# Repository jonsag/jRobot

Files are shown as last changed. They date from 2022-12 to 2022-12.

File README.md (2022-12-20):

# jRobot

My take on B-ROBOT found at https://github.com/jjrobots/B-ROBOT

## WiFI Remote

[https://play.google.com/store/apps/details?id=com.realwox.wifirccontroller&hl=en_US&gl=US](https://play.google.com/store/apps/details?id=com.realwox.wifirccontroller&hl=en_US&gl=US)
[https://play.google.com/store/apps/details?id=com.lacour.vincent.wificaresp8266&hl=en_US&gl=US](https://play.google.com/store/apps/details?id=com.lacour.vincent.wificaresp8266&hl=en_US&gl=US)

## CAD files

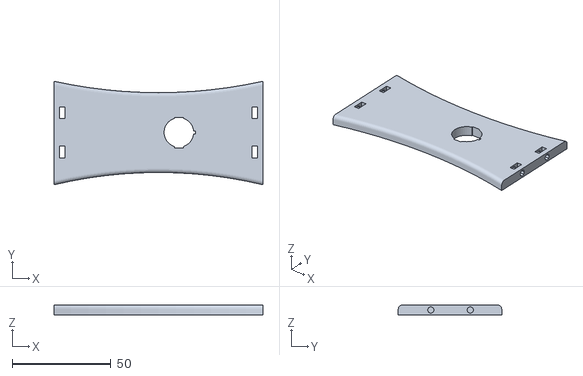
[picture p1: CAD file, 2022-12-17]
stl/top SHELF.stl
106.1 x 52.6 x 5.00

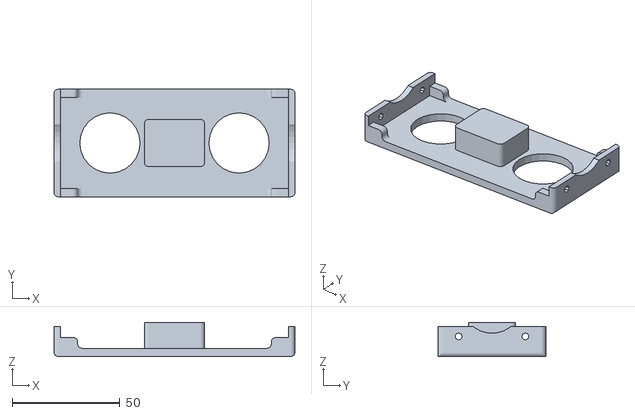
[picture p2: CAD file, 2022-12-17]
stl/motor SHELF.stl
112.0 x 50.0 x 15.9

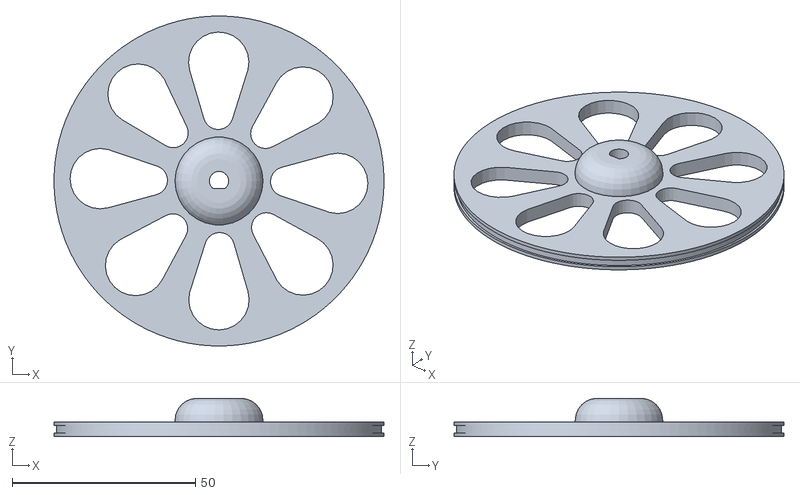
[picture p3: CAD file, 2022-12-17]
stl/Regular Wheel.stl
90.0 x 90.0 x 10.5

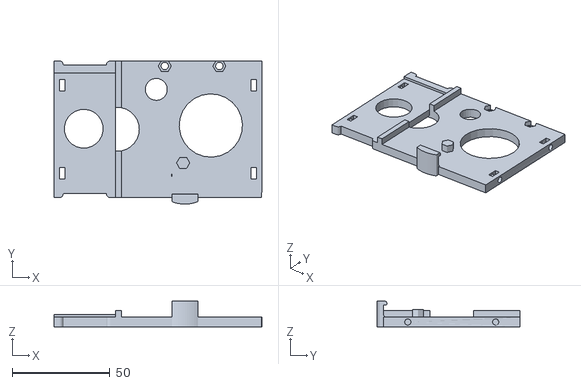
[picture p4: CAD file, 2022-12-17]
stl/Electronics SHELF.stl
106.2 x 73.1 x 13.2

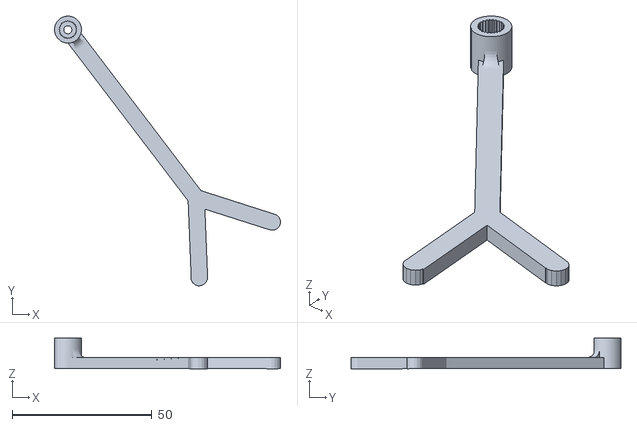
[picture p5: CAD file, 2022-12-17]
stl/regular ARM.stl
80.9 x 96.6 x 10.9

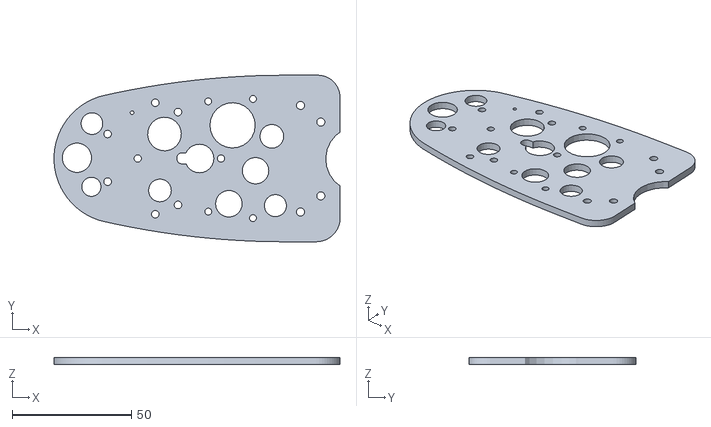
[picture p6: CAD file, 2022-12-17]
stl/Lateral.stl
120.1 x 70.0 x 3.00

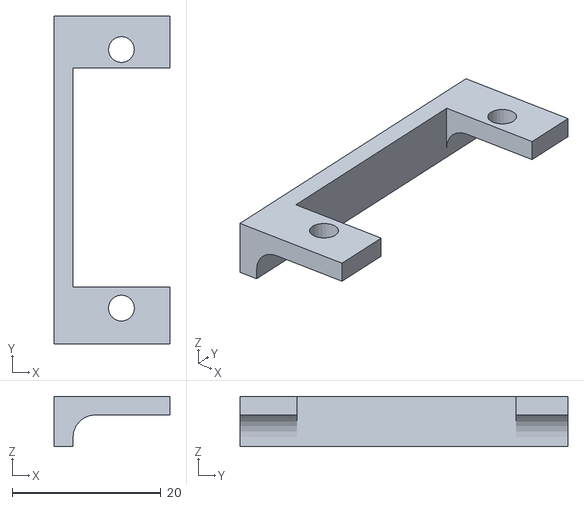
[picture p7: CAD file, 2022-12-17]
stl/servo holder.stl
15.5 x 44.0 x 6.78

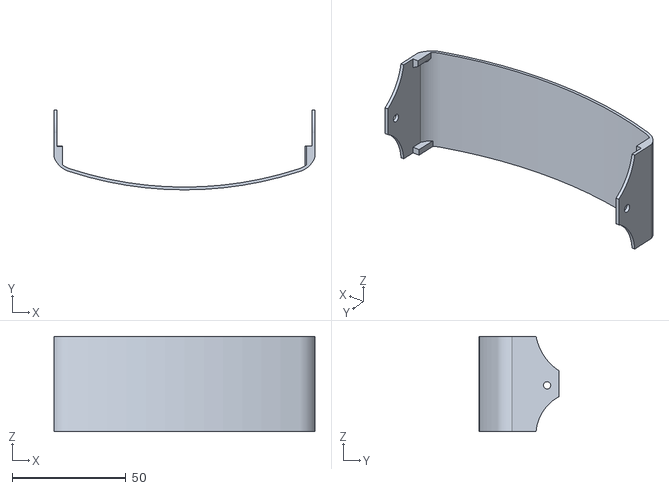
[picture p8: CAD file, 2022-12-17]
stl/Bumper.stl
114.5 x 35.0 x 41.9

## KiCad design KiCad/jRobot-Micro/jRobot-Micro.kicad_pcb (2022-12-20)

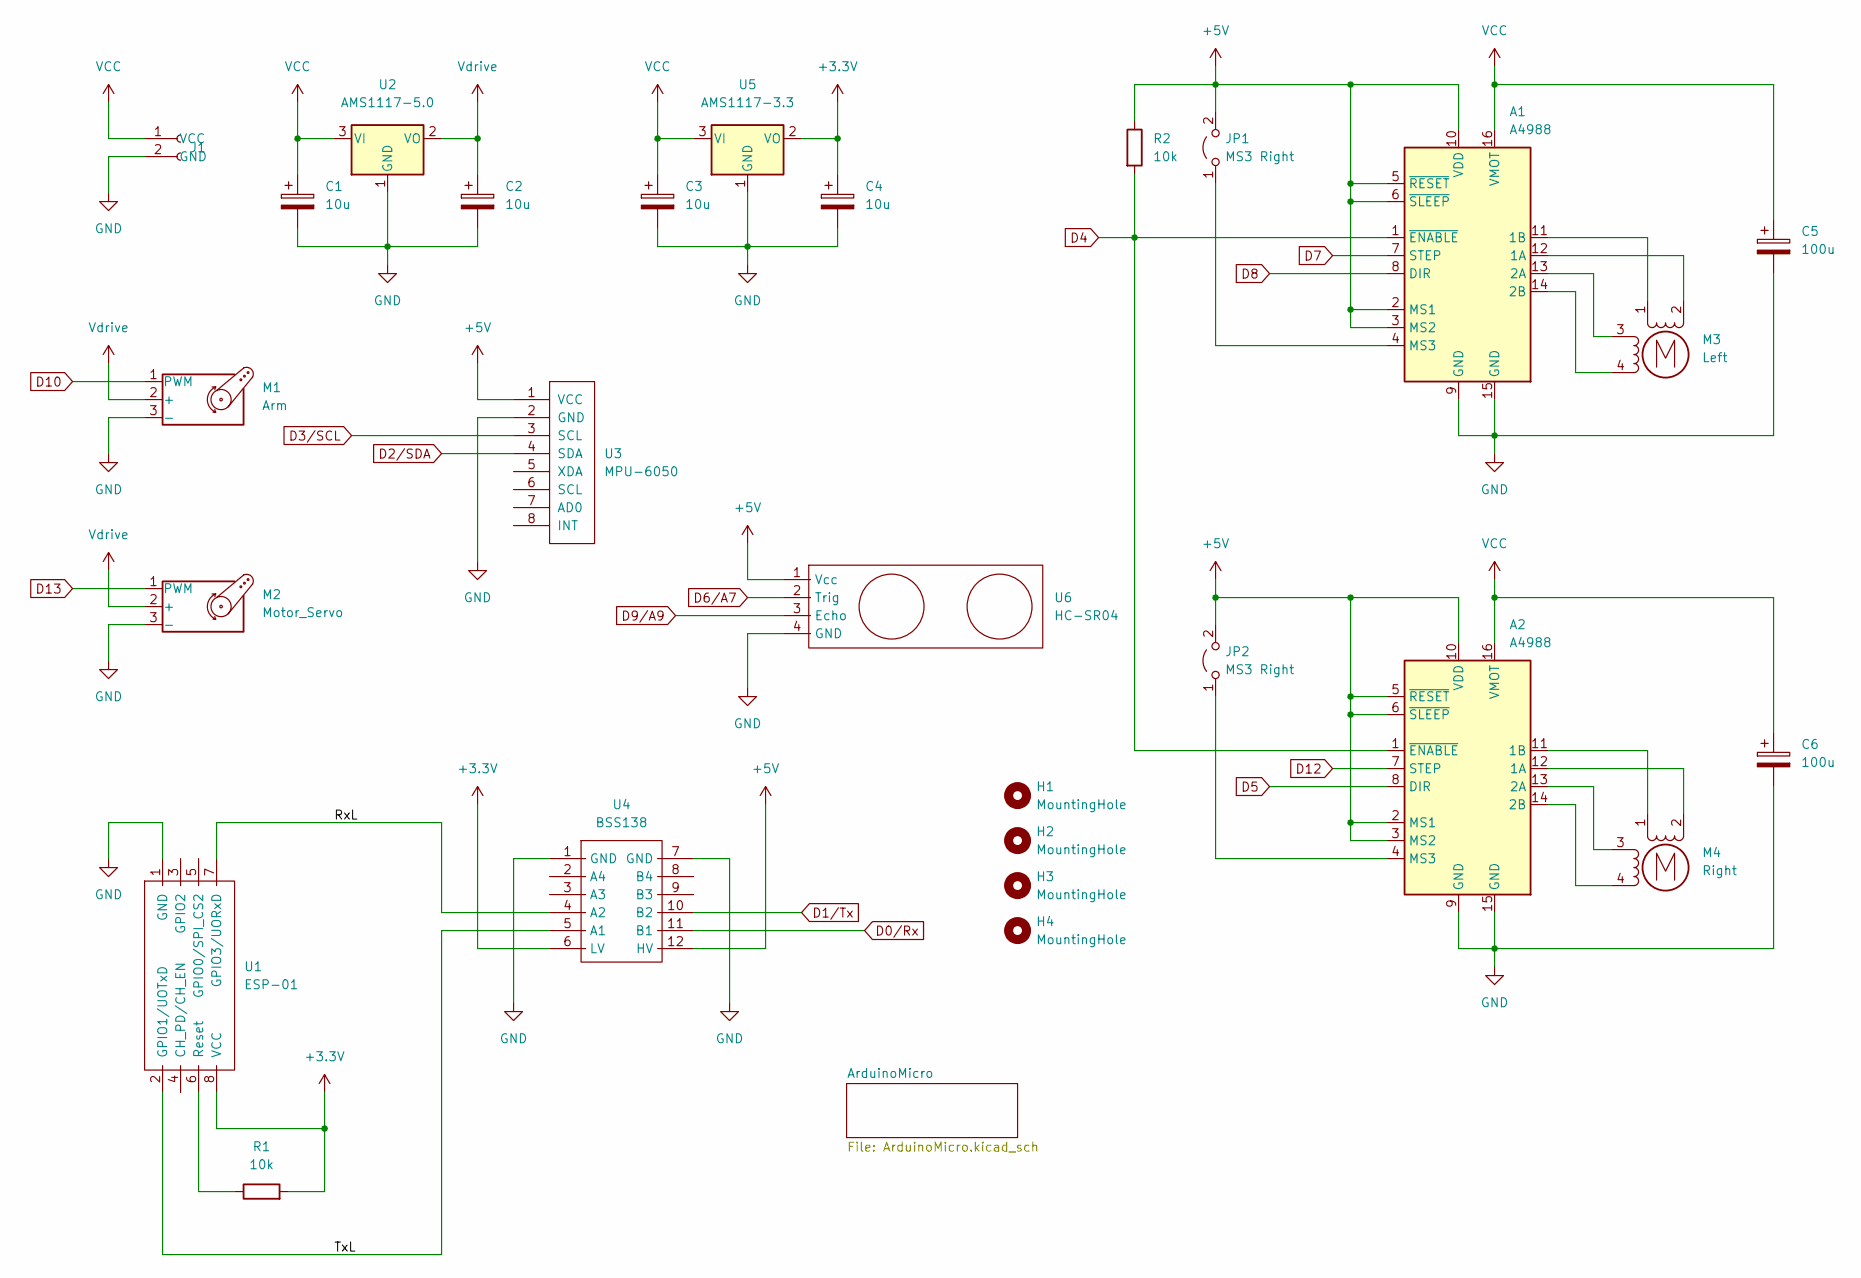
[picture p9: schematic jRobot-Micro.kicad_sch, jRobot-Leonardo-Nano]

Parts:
A1, A2: A4988; Pololu_Breakout-16_15.2x20.3mm_large
C1, C2, C3, C4: 10u; CP_Radial_D5.0mm_P2.00mm_larger
C5, C6: 100u; CP_Radial_D5.0mm_P2.00mm_larger
H1, H2, H3, H4: MountingHole; MountingHole_3.2mm_M3
J1: 2-pin_power_input_header
JP1, JP2: MS3 Right; Jumper_1x02_P2.54mm_large
M1: Arm; 3-pin JST Servo
M2: Motor_Servo
M3: Left; PhoenixPCB_2-Pole_Stepper_Connector
M4: Right; PhoenixPCB_2-Pole_Stepper_Connector
R1, R2: 10k; R_Axial_DIN0207_L6.3mm_D2.5mm_P10.16mm_Horizontal_large
U1: ESP-01; ESP-01_w_pin_socket_large
U2: AMS1117-5.0; SOT-223-3_TabPin2
U3: MPU-6050; GY-521_MPU6050_w_header_large
U4: BSS138; 4-channel_I2C_level_shifter_BSS138_large
U5: AMS1117-3.3; SOT-223-3_TabPin2
U6: HC-SR04; 4-pin JST HC-SR04 Sonar

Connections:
+3.3V: C4.1, R1.2, U1.8 (VCC), U4.6 (LV), U5.2 (VO); also elsewhere on the board
+5V: A1.2 (MS1), A1.3 (MS2), A1.5 (~RESET), A1.6 (~SLEEP), A1.10 (VDD), A2.2 (MS1), A2.3 (MS2), A2.5 (~RESET), A2.6 (~SLEEP), A2.10 (VDD), JP1.2 (B), JP2.2 (B), R2.1, U3.1 (VCC), U4.12 (HV), U6.1 (Vcc); also elsewhere on the board
/RxL: U1.7 (GPIO3/UORxD), U4.4 (A2)
/TxL: U1.2 (GPIO1/UOTxD), U4.5 (A1)
D0/Rx: U4.11 (B1); also elsewhere on the board
D1/Tx: U4.10 (B2); also elsewhere on the board
D2/SDA: U3.4 (SDA); also elsewhere on the board
D3/SCL: U3.3 (SCL); also elsewhere on the board
D4: A1.1 (~ENABLE), A2.1 (~ENABLE), R2.2
D5: A2.8 (DIR); also elsewhere on the board
D6/A7: U6.2 (Trig); also elsewhere on the board
D7: A1.7 (STEP); also elsewhere on the board
D8: A1.8 (DIR)
D9/A9: U6.3 (Echo); also elsewhere on the board
D10: M1.1 (PWM)
D12: A2.7 (STEP)
GND: A1.9 (GND), A1.15 (GND), A2.9 (GND), A2.15 (GND), C1.2, C2.2, C3.2, C4.2, C5.2, C6.2, J1.2 (GND), M1.3 (-), M2.3 (-), U1.1 (GND), U2.1 (GND), U3.2 (GND), U4.1 (GND), U4.7 (GND), U5.1 (GND), U6.4 (GND); also elsewhere on the board
unnamed: A1.4 (MS3), JP1.1 (A)
unnamed: A1.11 (1B), M3.1
unnamed: A1.12 (1A), M3.2 (-)
unnamed: A1.13 (2A), M3.3
unnamed: A1.14 (2B), M3.4
unnamed: A2.4 (MS3), JP2.1 (A)
unnamed: A2.11 (1B), M4.1
unnamed: A2.12 (1A), M4.2 (-)
unnamed: A2.13 (2A), M4.3
unnamed: A2.14 (2B), M4.4
unnamed: R1.1, U1.6 (Reset)
VCC: A1.16 (VMOT), A2.16 (VMOT), C1.1, C3.1, C5.1, C6.1, J1.1 (VCC), U2.3 (VI), U5.3 (VI); also elsewhere on the board
Vdrive: C2.1, M1.2 (+), M2.2 (+), U2.2 (VO)

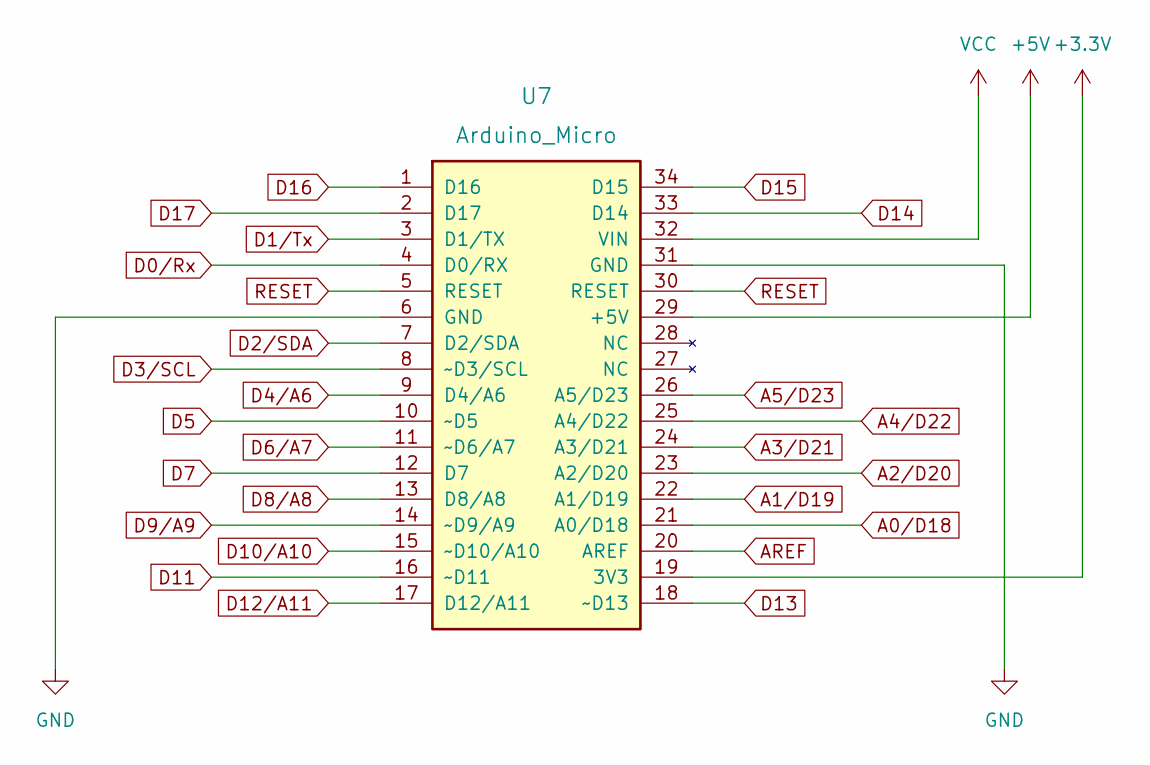
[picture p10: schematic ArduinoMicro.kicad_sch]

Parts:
U7: Arduino_Micro; Arduino_Micro large

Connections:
+3.3V: U7.19 (3V3); also elsewhere on the board
+5V: U7.29 (+5V); also elsewhere on the board
A0/D18: U7.21 (A0/D18)
A1/D19: U7.22 (A1/D19)
A2/D20: U7.23 (A2/D20)
A3/D21: U7.24 (A3/D21)
A4/D22: U7.25 (A4/D22)
A5/D23: U7.26 (A5/D23)
AREF: U7.20 (AREF)
D0/Rx: U7.4 (D0/RX); also elsewhere on the board
D1/Tx: U7.3 (D1/TX); also elsewhere on the board
D2/SDA: U7.7 (D2/SDA); also elsewhere on the board
D3/SCL: U7.8 (~D3/SCL); also elsewhere on the board
D4/A6: U7.9 (D4/A6)
D5: U7.10 (~D5); also elsewhere on the board
D6/A7: U7.11 (~D6/A7); also elsewhere on the board
D7: U7.12 (D7); also elsewhere on the board
D8/A8: U7.13 (D8/A8)
D9/A9: U7.14 (~D9/A9); also elsewhere on the board
D10/A10: U7.15 (~D10/A10)
D11: U7.16 (~D11)
D12/A11: U7.17 (D12/A11)
D13: U7.18 (~D13)
D14: U7.33 (D14)
D15: U7.34 (D15)
D16: U7.1 (D16)
D17: U7.2 (D17)
GND: U7.6 (GND), U7.31 (GND); also elsewhere on the board
RESET: U7.5 (RESET), U7.30 (RESET)
VCC: U7.32 (VIN); also elsewhere on the board

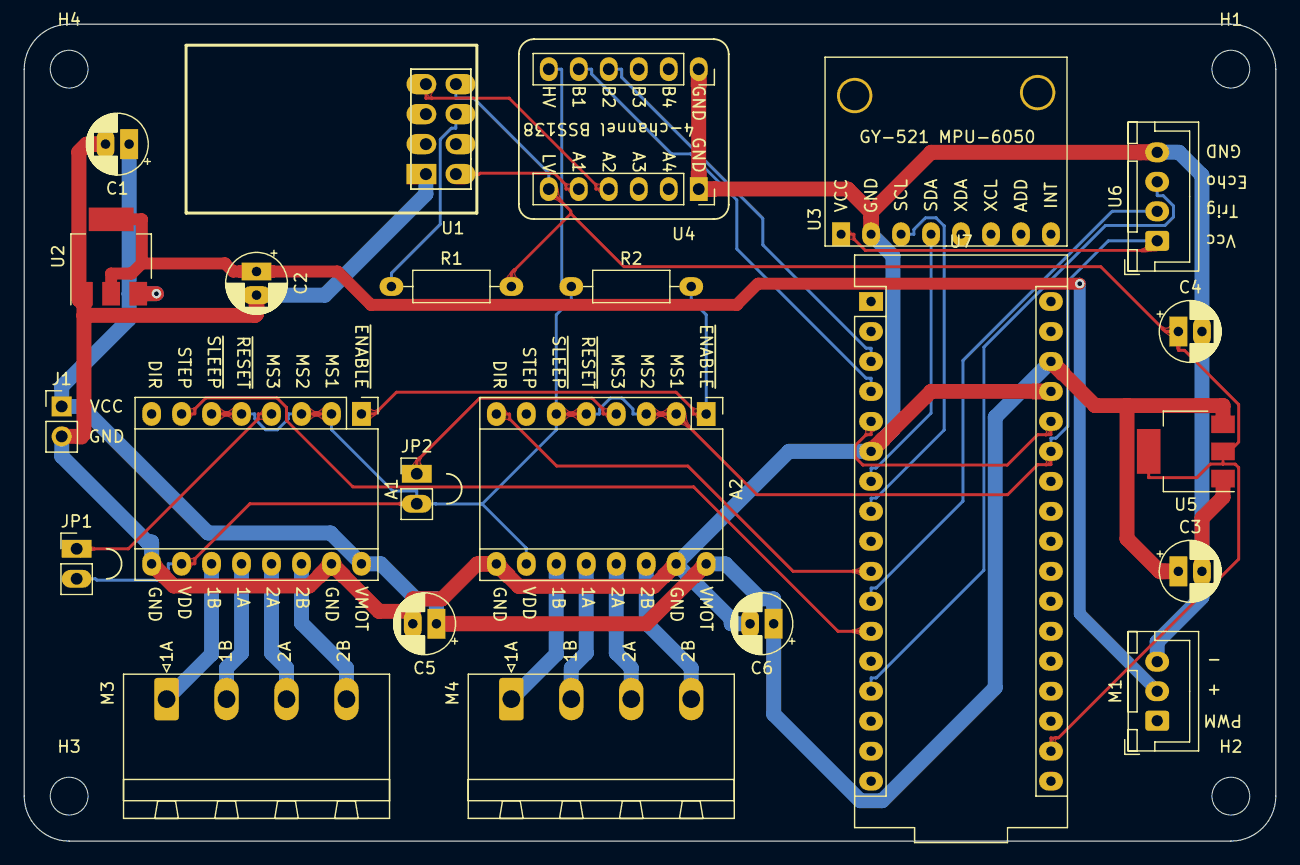
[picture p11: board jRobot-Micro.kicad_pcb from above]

Board: 2 copper layers, 106.0 x 69.2 mm, 27 parts (0 on the bottom side), 28 nets.

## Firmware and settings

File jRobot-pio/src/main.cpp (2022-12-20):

#include <Arduino.h>

// B-ROBOT  SELF BALANCE ARDUINO ROBOT WITH STEPPER MOTORS
// JJROBOTS BROBOT KIT: (Arduino Leonardo + BROBOT ELECTRONIC BRAIN v2 + STEPPER MOTOR drivers)
// This code is prepared for new BROBOT shield v2.0 with ESP8266 Wifi module
// You need to install libraries JJROBOTS_OSC, JJROBOTS_BROBOT, I2Cdev and MPU6050 (from Github repository)
// Author: JJROBOTS.COM (Jose Julio & Juan Pedro)
// Date: 02/09/2014
// Updated: 26/10/2015
// Version: 2.21
// License: GPL v2
// Project URL: http://jjrobots.com/b-robot (Features,documentation,build instructions,how it works, SHOP,...)
// New updates:
//   - New default parameters specially tuned for BROBOT EVO version
//   - Support for TouchMessages(/z). Main controls resets when user lift the fingers
//   - BROBOT sends the battery status to the interface
//   Remember to update the libraries and install the new TouchOSC layout
//  Thanks to our users on the forum for the new ideas. Specially sasa999, KomX, ...

// The board needs at least 10-15 seconds with no motion (robot steady) at beginning to give good values...
// MPU6050 IMU using internal DMP processor. Connected via I2C bus
// Angle calculations and control part is running at 200Hz from DMP solution
// DMP is using the gyro_bias_no_motion correction method.

// The robot is OFF when the angle is high (robot is horizontal). When you start raising the robot it
// automatically switch ON and start a RAISE UP procedure.
// You could RAISE UP the robot also with the robot arm servo [OPTIONAL] (Push1 on the interface)
// To switch OFF the robot you could manually put the robot down on the floor (horizontal)

// We use a standard PID controllers (Proportional, Integral derivative controller) for robot stability
// More info on the project page
// We have a PI controller for speed control and a PD controller for stability (robot angle)
// The output of the control (motors speed) is integrated so it´s really an acceleration not an speed.

// We control the robot from a WIFI module using OSC standard UDP messages (JJROBOTS_OSC library)
// You need an OSC app to control de robot (example: TouchOSC for IOS and Android)
// Join the module Wifi Access Point (by default: JJROBOTS) with your Smartphone/Tablet...
// Install the BROBOT layout into the OSC app (Touch OSC) and start play! (read the project page)
// OSC controls:
//    fader1: Throttle (0.0-1.0) OSC message: /1/fader1
//    fader2: Steering (0.0-1.0) OSC message: /1/fader2
//    push1: Move servo arm (and robot raiseup) OSC message /1/push1 [OPTIONAL]
//    if you enable the touchMessage on TouchOSC options, controls return to center automatically when you lift your fingers
//    toggle1: Enable PRO mode. On PRO mode steering and throttle are more aggressive
//    PAGE2: PID adjustments [optional][don´t touch if you don´t know what you are doing...;-) ]

#include "config.h"
#include "dmpFunctions.h"
#include "PIDController.h"
#include "delay.h"
#include "timers.h"
#include "motorControl.h"
#include "oscControl.h"
#include "ESPSetup.h"

// INITIALIZATION
void setup()
{
  // STEPPER PINS ON JJROBOTS BROBOT BRAIN BOARD
  pinMode(ENABLE_MOTORS_PIN, OUTPUT);    // ENABLE MOTORS
  pinMode(STEP_MOTOR_1_PIN, OUTPUT);    // STEP MOTOR 1 PORTE,6
  pinMode(DIR_MOTOR_1_PIN, OUTPUT);    // DIR MOTOR 1  PORTB,4
  pinMode(STEP_MOTOR_2_PIN, OUTPUT);   // STEP MOTOR 2 PORTD,6
  pinMode(DIR_MOTOR_2_PIN, OUTPUT);    // DIR MOTOR 2  PORTC,6
  digitalWrite(DISABLE_MOTORS_PIN, HIGH); // Disable motors

  pinMode(SERVO_1_PIN, OUTPUT); // Servo1 (arm)
  pinMode(SERVO_2_PIN, OUTPUT); // Servo2

  Serial.begin(115200); // Serial output to console

  // Wifi module initialization: Wifi module should be pre configured (use another sketch to configure the module)

  // Initialize I2C bus (MPU6050 is connected via I2C)
  Wire.begin();
  // I2C 400Khz fast mode
  TWSR = 0;
  TWBR = ((16000000L / I2C_SPEED) - 16) / 2;
  TWCR = 1 << TWEN;

#if DEBUG > 0
  delay(9000);
#else
  delay(2000);
#endif
  Serial.println("BROBOT by JJROBOTS v2.2");
  Serial.println("Initializing I2C devices...");
  // mpu.initialize();
  //  Manual MPU initialization... accel=2G, gyro=2000º/s, filter=20Hz BW, output=200Hz
  mpu.setClockSource(MPU6050_CLOCK_PLL_ZGYRO);
  mpu.setFullScaleGyroRange(MPU6050_GYRO_FS_2000);
  mpu.setFullScaleAccelRange(MPU6050_ACCEL_FS_2);
  mpu.setDLPFMode(MPU6050_DLPF_BW_10); // 10,20,42,98,188  // Default factor for BROBOT:10
  mpu.setRate(4);                      // 0=1khz 1=500hz, 2=333hz, 3=250hz 4=200hz
  mpu.setSleepEnabled(false);

  delay(500);
  Serial.println("Initializing DMP...");
  devStatus = mpu.dmpInitialize();
  if (devStatus == 0)
  {
    // turn on the DMP, now that it's ready
    Serial.println("Enabling DMP...");
    mpu.setDMPEnabled(true);
    mpuIntStatus = mpu.getIntStatus();
    dmpReady = true;
  }
  else
  { // ERROR!
    // 1 = initial memory load failed
    // 2 = DMP configuration updates failed
    // (if it's going to break, usually the code will be 1)
    Serial.print("DMP Initialization failed (code ");
    Serial.print(devStatus);
    Serial.println(")");
  }

  // Gyro calibration
  // The robot must be steady during initialization
  delay(500);
  Serial.println("Gyro calibration!!  Dont move the robot in 10 seconds... ");
  delay(500);

#ifdef WIFI_ESP
  // With the new ESP8266 WIFI MODULE WE NEED TO MAKE AN INITIALIZATION PROCESS
  Serial.println("Initializing ESP Wifi Module...");
  Serial.println("WIFI RESET");
  Serial1_flush();
  Serial1_print("+++"); // To ensure we exit the transparent transmission mode
  delay(100);
  ESPsendCommand("AT", "OK", 1);
  ESPsendCommand("AT+RST", "OK", 2); // ESP Wifi module RESET
  ESPwait("ready", 6);
  ESPsendCommand("AT+GMR", "OK", 5);
  Serial1_println("AT+CIPSTAMAC?");
  ESPgetMac();
  Serial.print("MAC:");
  Serial.println(MAC);
  delay(250);
  ESPsendCommand("AT+CWQAP", "OK", 3);
  ESPsendCommand("AT+CWMODE=2", "OK", 3); // Soft AP mode
  // Generate Soft AP. SSID=JJROBOTS, PASS=87654321
  char *cmd = "AT+CWSAP=\"JJROBOTS_XX\",\"87654321\",5,3";
  // Update XX characters with MAC address (last 2 characters)
  cmd[19] = MAC[10];
  cmd[20] = MAC[11];
  // const char cmd[50] = "AT+CWSAP=\"JJROBOTS_"+MAC.substring(MAC.length()-2)+"\",\"87654321\",5,3";
  ESPsendCommand(cmd, "OK", 6);
  // Start UDP SERVER on port 2222
  Serial.println("Start UDP server at port 2222");
  ESPsendCommand("AT+CIPMUX=0", "OK", 3);  // Single connection mode
  ESPsendCommand("AT+CIPMODE=1", "OK", 3); // Transparent mode
  // ESPsendCommand("AT+CIPSTART=\"UDP\",\"0\",2223,2222,0", "OK", 3);
  ESPsendCommand("AT+CIPSTART=\"UDP\",\"192.168.4.2\",2223,2222,0", "OK", 3);
  delay(250);
  ESPsendCommand("AT+CIPSEND", ">", 2); // Start transmission (transparent mode)
  delay(5000);                          // Time to settle things... the bias_from_no_motion algorithm needs some time to take effect and reset gyro bias.
#else
  delay(10000); // Time to settle things... the bias_from_no_motion algorithm needs some time to take effect and reset gyro bias.
#endif

  // Verify connection
  Serial.println("Testing device connections...");
  Serial.println(mpu.testConnection() ? "MPU6050 connection successful" : "MPU6050 connection failed");
  timer_old = millis();

  // Init servos
  Serial.println("Servo initialization...");
  BROBOT.initServo();
  BROBOT.moveServo1(SERVO_AUX_NEUTRO);

  // STEPPER MOTORS INITIALIZATION
  Serial.println("Stepper motors initialization...");
  // MOTOR1 => TIMER1
  TCCR1A = 0;                          // Timer1 CTC mode 4, OCxA,B outputs disconnected
  TCCR1B = (1 << WGM12) | (1 << CS11); // Prescaler=8, => 2Mhz
  OCR1A = ZERO_SPEED;                  // Motor stopped
  dir_M1 = 0;
  TCNT1 = 0;

  // MOTOR2 => TIMER3
  TCCR3A = 0;                          // Timer3 CTC mode 4, OCxA,B outputs disconnected
  TCCR3B = (1 << WGM32) | (1 << CS31); // Prescaler=8, => 2Mhz
  OCR3A = ZERO_SPEED;                  // Motor stopped
  dir_M2 = 0;
  TCNT3 = 0;

  // Adjust sensor fusion gain
  Serial.println("Adjusting DMP sensor fusion gain...");
  dmpSetSensorFusionAccelGain(0x20);

  delay(200);

  // Enable stepper drivers and TIMER interrupts
  digitalWrite(4, LOW); // Enable stepper drivers
  // Enable TIMERs interrupts
  TIMSK1 |= (1 << OCIE1A); // Enable Timer1 interrupt
  TIMSK3 |= (1 << OCIE1A); // Enable Timer1 interrupt

  // Little motor vibration and servo move to indicate that robot is ready
  for (uint8_t k = 0; k < 5; k++)
  {
    setMotorSpeedM1(5);
    setMotorSpeedM2(5);
    BROBOT.moveServo1(SERVO_AUX_NEUTRO + 100);
    delay(200);
    setMotorSpeedM1(-5);
    setMotorSpeedM2(-5);
    BROBOT.moveServo1(SERVO_AUX_NEUTRO - 100);
    delay(200);
  }
  BROBOT.moveServo1(SERVO_AUX_NEUTRO);

  Serial.print("BATTERY:");
  Serial.println(BROBOT.readBattery());

  // OSC initialization
  OSC.fadder1 = 0.5;
  OSC.fadder2 = 0.5;

  Serial.println("Let´s start...");

  mpu.resetFIFO();
  timer_old = millis();
  Robot_shutdown = false;
  mode = 0;
}

// MAIN LOOP
void loop()
{
  // If we run out of battery, we do nothing... STOP
#if SHUTDOWN_WHEN__OFF == 1
  if (Robot_shutdown)
    return;
#endif

  debug_counter++;
  OSC.MsgRead(); // Read UDP OSC messages
  if (OSC.newMessage)
  {
    OSC.newMessage = 0;
    if (OSC.page == 1) // Get commands from user (PAGE1 are user commands: throttle, steering...)
    {
      OSC.newMessage = 0;
      throttle = (OSC.fadder1 - 0.5) * max_throttle;
      // We add some exponential on steering to smooth the center band
      steering = OSC.fadder2 - 0.5;
      if (steering > 0)
        steering = (steering * steering + 0.5 * steering) * max_steering;
      else
        steering = (-steering * steering + 0.5 * steering) * max_steering;

      modifing_control_parameters = false;
      if ((mode == 0) && (OSC.toggle1))
      {
        // Change to PRO mode
        max_throttle = MAX_THROTTLE_PRO;
        max_steering = MAX_STEERING_PRO;
        max_target_angle = MAX_TARGET_ANGLE_PRO;
        mode = 1;
      }
      if ((mode == 1) && (OSC.toggle1 == 0))
      {
        // Change to NORMAL mode
        max_throttle = MAX_THROTTLE;
        max_steering = MAX_STEERING;
        max_target_angle = MAX_TARGET_ANGLE;
        mode = 0;
      }
    }
#if DEBUG == 1
    Serial.print(throttle);
    Serial.print(" ");
    Serial.println(steering);
#endif
  } // End new OSC message

  timer_value = millis();

  // New DMP Orientation solution?
  fifoCount = mpu.getFIFOCount();
  if (fifoCount >= 18)
  {
    if (fifoCount > 18) // If we have more than one packet we take the easy path: discard the buffer and wait for the next one
    {
      Serial.println("FIFO RESET!!");
      mpu.resetFIFO();
      return;
    }
    loop_counter++;
    slow_loop_counter++;
    dt = (timer_value - timer_old);
    timer_old = timer_value;

    angle_adjusted_Old = angle_adjusted;
    // Get new orientation angle from IMU (MPU6050)
    angle_adjusted = dmpGetPhi();

#if DEBUG == 8
    Serial.print(throttle);
    Serial.print(" ");
    Serial.print(steering);
    Serial.print(" ");
    Serial.println(mode);
#endif

#if DEBUG == 1
    Serial.println(angle_adjusted);
#endif
    // Serial.print("\t");
    mpu.resetFIFO(); // We always reset FIFO

    // We calculate the estimated robot speed:
    // Estimated_Speed = angular_velocity_of_stepper_motors(combined) - angular_velocity_of_robot(angle measured by IMU)
    actual_robot_speed_Old = actual_robot_speed;
    actual_robot_speed = (speed_M1 + speed_M2) / 2; // Positive: forward

    int16_t angular_velocity = (angle_adjusted - angle_adjusted_Old) * 90.0;                    // 90 is an empirical extracted factor to adjust for real units
    int16_t estimated_speed = -actual_robot_speed_Old - angular_velocity;                       // We use robot_speed(t-1) or (t-2) to compensate the delay
    estimated_speed_filtered = estimated_speed_filtered * 0.95 + (float)estimated_speed * 0.05; // low pass filter on estimated speed

#if DEBUG == 2
    Serial.print(" ");
    Serial.println(estimated_speed_filtered);
#endif
    // SPEED CONTROL: This is a PI controller.
    //    input:user throttle, variable: estimated robot speed, output: target robot angle to get the desired speed
    target_angle = speedPIControl(dt, estimated_speed_filtered, throttle, Kp_thr, Ki_thr);
    target_angle = constrain(target_angle, -max_target_angle, max_target_angle); // limited output

#if DEBUG == 3
    Serial.print(" ");
    Serial.println(estimated_speed_filtered);
    Serial.print(" ");
    Serial.println(target_angle);
#endif

    // Stability control: This is a PD controller.
    //    input: robot target angle(from SPEED CONTROL), variable: robot angle, output: Motor speed
    //    We integrate the output (summatory), so the output is really the motor acceleration, not motor speed.
    control_output += stabilityPDControl(dt, angle_adjusted, target_angle, Kp, Kd);
    control_output = constrain(control_output, -MAX_CONTROL_OUTPUT, MAX_CONTROL_OUTPUT); // Limit max output from control

    // The steering part from the user is injected directly on the output
    motor1 = control_output + steering;
    motor2 = control_output - steering;

    // Limit max speed (control output)
    motor1 = constrain(motor1, -MAX_CONTROL_OUTPUT, MAX_CONTROL_OUTPUT);
    motor2 = constrain(motor2, -MAX_CONTROL_OUTPUT, MAX_CONTROL_OUTPUT);

    // NOW we send the commands to the motors
    if ((angle_adjusted < 76) && (angle_adjusted > -76)) // Is robot ready (upright?)
    {
      // NORMAL MODE
      digitalWrite(4, LOW); // Motors enable
      setMotorSpeedM1(motor1);
      setMotorSpeedM2(motor2);

      // Push1 Move servo arm
      if (OSC.push1) // Move arm
      {
        // Update to correct bug when the robot is lying backward
        if (angle_adjusted > -40)
          BROBOT.moveServo1(SERVO_MIN_PULSEWIDTH + 100);
        else
          BROBOT.moveServo1(SERVO_MAX_PULSEWIDTH + 100);
      }
      else
        BROBOT.moveServo1(SERVO_AUX_NEUTRO);

      // Push2 reset controls to neutral position
      if (OSC.push2)
      {
        OSC.fadder1 = 0.5;
        OSC.fadder2 = 0.5;
      }

      // Normal condition?
      if ((angle_adjusted < 45) && (angle_adjusted > -45))
      {
        Kp = Kp_user; // Default user control gains
        Kd = Kd_user;
        Kp_thr = Kp_thr_user;
        Ki_thr = Ki_thr_user;
      }
      else // We are in the raise up procedure => we use special control parameters
      {
        Kp = KP_RAISEUP; // CONTROL GAINS FOR RAISE UP
        Kd = KD_RAISEUP;
        Kp_thr = KP_THROTTLE_RAISEUP;
        Ki_thr = KI_THROTTLE_RAISEUP;
      }
    }
    else // Robot not ready (flat), angle > 70º => ROBOT OFF
    {
      digitalWrite(4, HIGH); // Disable motors
      setMotorSpeedM1(0);
      setMotorSpeedM2(0);
      PID_errorSum = 0; // Reset PID I term
      Kp = KP_RAISEUP;  // CONTROL GAINS FOR RAISE UP
      Kd = KD_RAISEUP;
      Kp_thr = KP_THROTTLE_RAISEUP;
      Ki_thr = KI_THROTTLE_RAISEUP;

      // if we pulse push1 button we raise up the robot with the servo arm
      if (OSC.push1)
      {
        // Because we know the robot orientation (face down of face up), we move the servo in the appropiate direction for raise up
        if (angle_adjusted > 0)
          BROBOT.moveServo1(SERVO_MIN_PULSEWIDTH);
        else
          BROBOT.moveServo1(SERVO_MAX_PULSEWIDTH);
      }
      else
        BROBOT.moveServo1(SERVO_AUX_NEUTRO);
    }
    // Check for new user control parameters
    readControlParameters();

  } // End of new IMU data

  // Medium loop 40Hz
  if (loop_counter >= 5)
  {
    loop_counter = 0;
    // We do nothing here now...
#if DEBUG == 10
    Serial.print(angle_adjusted);
    Serial.print(" ");
    Serial.println(debugVariable);
#endif
  } // End of medium loop

  if (slow_loop_counter >= 99) // 2Hz
  {
    slow_loop_counter = 0;
    // Read  status
#if BATTERY_CHECK == 1
    int BatteryValue = BROBOT.readBattery();
    sendBattery_counter++;
    if (sendBattery_counter >= 10)
    { // Every 5 seconds we send a message
      sendBattery_counter = 0;
#if LIPOBATT == 0
      // From >10.6 volts (100%) to 9.2 volts (0%) (aprox)
      float value = constrain((BatteryValue - 92) / 14.0, 0.0, 1.0);
#else
      // For Lipo battery use better this config: (From >11.5v (100%) to 9.5v (0%)
      float value = constrain((BatteryValue - 95) / 20.0, 0.0, 1.0);
#endif
      // Serial.println(value);
      OSC.MsgSend("/1/rotary1\0\0,f\0\0\0\0\0\0", 20, value);
    }
    // if (Battery_value < BATTERY_WARNING){
    //   Serial.print("LOW BAT!! ");
    //   }
#endif // BATTERY_CHECK
#if DEBUG == 6
    Serial.print("B:");
    Serial.println(BatteryValue);
#endif
#if SHUTDOWN_WHEN_BATTERY_OFF == 1

    if (BROBOT.readBattery(); < BATTERY_SHUTDOWN)
    {
      // Robot shutdown !!!
      Serial.println("LOW BAT!! SHUTDOWN");
      Robot_shutdown = true;
      // Disable steppers
      digitalWrite(4, HIGH); // Disable motors
    }
#endif

  } // End of slow loop
}

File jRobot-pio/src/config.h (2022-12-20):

#define WIFI_ESP // New WIFI ESP8266 Module. Comment this line if you are using the old Wifi module (RN-171)

#include <JJROBOTS_OSC.h>
#include <JJROBOTS_BROBOT.h>
#include <Wire.h>
#include <I2Cdev.h>               // I2Cdev lib from www.i2cdevlib.com
#include <JJ_MPU6050_DMP_6Axis.h> // Modified version of the MPU6050 library to work with DMP (see comments inside)
// This version optimize the FIFO (only contains quaternion) and minimize code size

// PINS
#define ENABLE_MOTORS_PIN 4
#define STEP_MOTOR_1_PIN 7
#define DIR_MOTOR_1_PIN 8
#define STEP_MOTOR_2_PIN 12
#define DIR_MOTOR_2_PIN 5
#define DISABLE_MOTORS_PIN 4

#define SERVO_1_PIN 10
#define SERVO_2_PIN 13

#define SONAR_TRIG_PIN 6
#define SONAR_ECHO_PIN 9

// NORMAL MODE PARAMETERS (MAXIMUM SETTINGS)
#define MAX_THROTTLE 580
#define MAX_STEERING 150
#define MAX_TARGET_ANGLE 12

// PRO MODE = MORE AGGRESSIVE (MAXIMUM SETTINGS)
#define MAX_THROTTLE_PRO 980 // 680
#define MAX_STEERING_PRO 250
#define MAX_TARGET_ANGLE_PRO 40 // 20

// Default control terms
#define KP 0.19
#define KD 28
#define KP_THROTTLE 0.07
#define KI_THROTTLE 0.04

// Control gains for raiseup (the raiseup movement require special control parameters)
#define KP_RAISEUP 0.16
#define KD_RAISEUP 36
#define KP_THROTTLE_RAISEUP 0 // No speed control on raiseup
#define KI_THROTTLE_RAISEUP 0.0

#define MAX_CONTROL_OUTPUT 500

// Servo definitions
#define SERVO_AUX_NEUTRO 1550 // Servo neutral position
#define SERVO_MIN_PULSEWIDTH 650
#define SERVO_MAX_PULSEWIDTH 2600

// Battery management [optional]. This is not needed for alkaline or Ni-Mh batteries but useful for if you use lipo batteries
#define BATTERY_CHECK 1             // 0: No  check, 1: check (send message to interface)
#define LIPOBATT 0                  // Default 0: No Lipo batt 1: Lipo batt (to adjust battery monitor range)
#define BATTERY_WARNING 105         // (10.5 volts) aprox [for lipo batts, disable by default]
#define BATTERY_SHUTDOWN 95         // (9.5 volts) [for lipo batts]
#define SHUTDOWN_WHEN_BATTERY_OFF 0 // 0: Not used, 1: Robot will shutdown when battery is off (BATTERY_CHECK SHOULD BE 1)

#define DEBUG 0 // 0 = No debug info (default)

#define CLR(x, y) (x &= (~(1 << y)))
#define SET(x, y) (x |= (1 << y))

#define ZERO_SPEED 65535
#define MAX_ACCEL 7 // Maximum motor acceleration (MAX RECOMMENDED VALUE: 8) (default:7)

#define MICROSTEPPING 16 // 8 or 16 for 1/8 or 1/16 driver microstepping (default:16)

#define I2C_SPEED 400000L // 400kHz I2C speed

#define RAD2GRAD 57.2957795
#define GRAD2RAD 0.01745329251994329576923690768489

#define ITERM_MAX_ERROR 25 // Iterm windup constants for PI control //40
#define ITERM_MAX 8000     // 5000

bool Robot_shutdown = false; // Robot shutdown flag => Out of

String MAC; // MAC address of Wifi module

// MPU control/status vars
bool dmpReady = false;  // set true if DMP init was successful
uint8_t mpuIntStatus;   // holds actual interrupt status byte from MPU
uint8_t devStatus;      // return status after each device operation (0 = success, !0 = error)
uint16_t packetSize;    // expected DMP packet size (for us 18 bytes)
uint16_t fifoCount;     // count of all bytes currently in FIFO
uint8_t fifoBuffer[18]; // FIFO storage buffer
Quaternion q;

uint8_t loop_counter;        // To generate a medium loop 40Hz
uint8_t slow_loop_counter;   // slow loop 2Hz
uint8_t sendBattery_counter; // To send battery status

long timer_old;
long timer_value;
int debug_counter;
float debugVariable;
float dt;

// class default I2C address is 0x68 for MPU6050
MPU6050 mpu;

// Angle of the robot (used for stability control)
float angle_adjusted;
float angle_adjusted_Old;

// Default control values from constant definitions
float Kp = KP;
float Kd = KD;
float Kp_thr = KP_THROTTLE;
float Ki_thr = KI_THROTTLE;
float Kp_user = KP;
float Kd_user = KD;
float Kp_thr_user = KP_THROTTLE;
float Ki_thr_user = KI_THROTTLE;
bool newControlParameters = false;
bool modifing_control_parameters = false;
float PID_errorSum;
float PID_errorOld = 0;
float PID_errorOld2 = 0;
float setPointOld = 0;
float target_angle;
float throttle;
float steering;
float max_throttle = MAX_THROTTLE;
float max_steering = MAX_STEERING;
float max_target_angle = MAX_TARGET_ANGLE;
float control_output;

uint8_t mode; // mode = 0 Normal mode, mode = 1 Pro mode (More aggressive)

int16_t motor1;
int16_t motor2;

int16_t speed_M1, speed_M2; // Actual speed of motors
int8_t dir_M1, dir_M2;      // Actual direction of steppers motors
int16_t actual_robot_speed; // overall robot speed (measured from steppers speed)
int16_t actual_robot_speed_Old;
float estimated_speed_filtered; // Estimated robot speed

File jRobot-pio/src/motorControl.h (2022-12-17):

// Set speed of Stepper Motor1
// tspeed could be positive or negative (reverse)
void setMotorSpeedM1(int16_t tspeed)
{
    long timer_period;
    int16_t speed;

    // Limit max speed?

    // WE LIMIT MAX ACCELERATION of the motors
    if ((speed_M1 - tspeed) > MAX_ACCEL)
        speed_M1 -= MAX_ACCEL;
    else if ((speed_M1 - tspeed) < -MAX_ACCEL)
        speed_M1 += MAX_ACCEL;
    else
        speed_M1 = tspeed;

#if MICROSTEPPING == 16
    speed = speed_M1 * 46; // Adjust factor from control output speed to real motor speed in steps/second
#else
    speed = speed_M1 * 23; // 1/8 Microstepping
#endif

    if (speed == 0)
    {
        timer_period = ZERO_SPEED;
        dir_M1 = 0;
    }
    else if (speed > 0)
    {
        timer_period = 2000000 / speed; // 2Mhz timer
        dir_M1 = 1;
        SET(PORTB, 4); // DIR Motor 1 (Forward)
    }
    else
    {
        timer_period = 2000000 / -speed;
        dir_M1 = -1;
        CLR(PORTB, 4); // Dir Motor 1
    }
    if (timer_period > 65535) // Check for minimum speed (maximum period without overflow)
        timer_period = ZERO_SPEED;

    OCR1A = timer_period;
    // Check  if we need to reset the timer...
    if (TCNT1 > OCR1A)
        TCNT1 = 0;
}

// Set speed of Stepper Motor2
// tspeed could be positive or negative (reverse)
void setMotorSpeedM2(int16_t tspeed)
{
    long timer_period;
    int16_t speed;

    // Limit max speed?

    // WE LIMIT MAX ACCELERATION of the motors
    if ((speed_M2 - tspeed) > MAX_ACCEL)
        speed_M2 -= MAX_ACCEL;
    else if ((speed_M2 - tspeed) < -MAX_ACCEL)
        speed_M2 += MAX_ACCEL;
    else
        speed_M2 = tspeed;

#if MICROSTEPPING == 16
    speed = speed_M2 * 46; // Adjust factor from control output speed to real motor speed in steps/second
#else
    speed = speed_M2 * 23; // 1/8 Microstepping
#endif

    if (speed == 0)
    {
        timer_period = ZERO_SPEED;
        dir_M2 = 0;
    }
    else if (speed > 0)
    {
        timer_period = 2000000 / speed; // 2Mhz timer
        dir_M2 = 1;
        CLR(PORTC, 6); // Dir Motor2 (Forward)
    }
    else
    {
        timer_period = 2000000 / -speed;
        dir_M2 = -1;
        SET(PORTC, 6); // DIR Motor 2
    }
    if (timer_period > 65535) // Check for minimum speed (maximum period without overflow)
        timer_period = ZERO_SPEED;

    OCR3A = timer_period;
    // Check  if we need to reset the timer...
    if (TCNT3 > OCR3A)
        TCNT3 = 0;
}

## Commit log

2022-12-20 arduino micro
    [Arduino-UNO.kicad_sch, ArduinoMicro.kicad_sch, jRobot-Leonardo-Nano.kicad_pcb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]
2022-12-20 moved pin definitions to config
